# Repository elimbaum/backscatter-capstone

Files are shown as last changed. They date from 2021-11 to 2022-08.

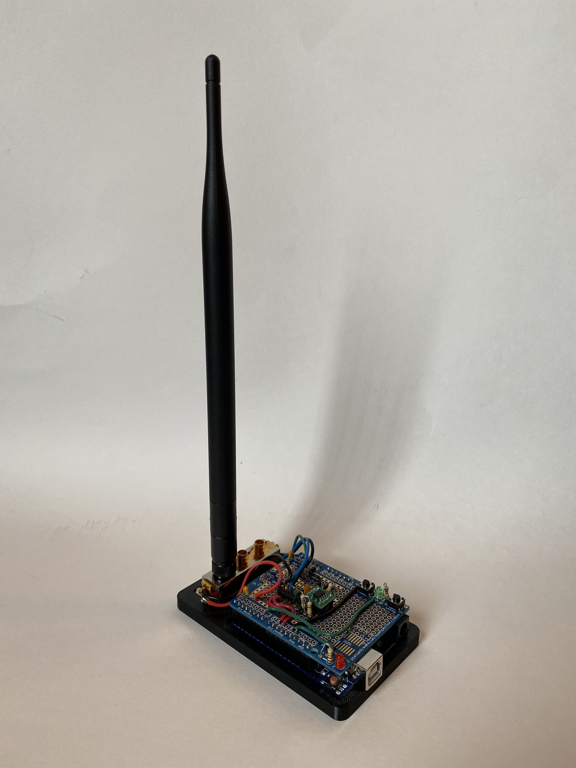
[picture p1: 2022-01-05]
img/full antenna.jpeg

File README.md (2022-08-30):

# Low-power Backscatter Sensor Communications

*NSAP Capstone Project, 2021*

Eli Baum

Full report is available in `backscatter capstone.docx`.

Repo layout:

- `arduino`
    - Various experiments for the transmitter module.
    - Final prototype is in `full_proto`, using utilty functions in `util`
- `flowgraphs`
    - Various GNUradio flowgraphs
    - `proto/proto_decode.grc` is used to ingest samples from SDR for final prototype.
- `img`: images for report
- `print/case`: 3d printed transmitter enclosure
- `processing`
    - Various python experiments and decoders
    - Final prototype is `fm0/fm0_proto.py`
- `pseudocode`
    - explanatory pseudocode for both the transmitter and receiver

> MITRE Public Release Case Number: 22-2535

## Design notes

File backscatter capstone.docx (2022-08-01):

| MP220434 MITRE PRODUCT
| Low-Power Backscatter Sensor Communications
Project No.: GNA051.N300.301.CA | National Security Accelerator Program Capstone Project
The views, opinions and/or findings contained in this report are those of The MITRE Corporation and should not be construed as an official government position, policy, or decision, unless designated by other documentation. ©2022 The MITRE Corporation. All rights reserved. McLean, VA | Eli Baum January 2022

Abstract

Wireless communications systems are frequently constrained by size and power. Occasionally, it may be desirable to communicate with extremely small, low-power systems. Here, we present a backscatter sensor communications platform, which modulates and reflects ambient radio frequency signals, rather than radiating its own signals in the manner of a standard radio transmitter. Our prototype system can communicate at approximately one kilobit per second over a distance of 1.3 meters. We draw on past research to show that more advanced schemes could permit greater transmission speeds over more useful distances. One possible application for such technology includes distributed low-power sensing.

Acknowledgments

I would like to thank Dr. Michael Balazs, Andy Chapman, and Terri Roberts of MITRE’s National Security Accelerator Program for their support and encouragement.

Samantha Palazzolo, Terry Roberts, Evan Ding, and Eric Renda provided invaluable technical guidance, and helped me find my footing in the early days of my career at MITRE.

Table of Contents

# 1 Introduction

Wireless communications systems require significant power and can be rather large due to the analog circuitry required to modulate and amplify radio signals. Here, we propose a method of using backscatter technology to build extremely low-power wireless sensors. Without the normal requirements of radio transmitters, these backscatter sensors can be small, cheap, and long-lived; furthermore, since they emit no power, they are difficult for an adversary to detect.

A backscatter transmitter modulates reflected radio signals from another source, rather than radiating signals that it generates. Since the transmitter must do nothing more than switch a transistor at a given frequency, it requires very little power: the power requirements for communication are shifted to the signal source (or “illuminator”) and processing is fully offloaded to a receiver, which may be attached to larger ground, air, or maritime platforms, where power and size are less constrained.

Backscatter systems can also be cheaply manufactured to provide distributed sensing capabilities. Users could distribute thousands of sensors across an area of interest and fly data-collection drones over the sensor field. Alternatively, a fixed station could read data in real time from sensors at a distance. Such deployments have already been validated in a prototype soil-moisture sensing network.[^1]

In this prototype, a software-defined radio (SDR) is used to generate a fixed-frequency tone at 915 MHz. The sensor modulates data at approximately 150 kHz; the receive side of the SDR is therefore tuned to 915.15 MHz. We attach a magnetic sensor to demonstrate one possible application. However, this demonstration is not the limit of backscatter sensing technology: academic research has demonstrated the ability for relatively complex backscatter systems to be powered entirely by harvested ambient radio frequency energy,[^2] while other studies have used custom waveforms to receive backscatter signals over distances of more than a kilometer.[^3] Furthermore, other environmental illuminators may be used, including broadcast TV or radar, removing the requirement for a separate transmitter.

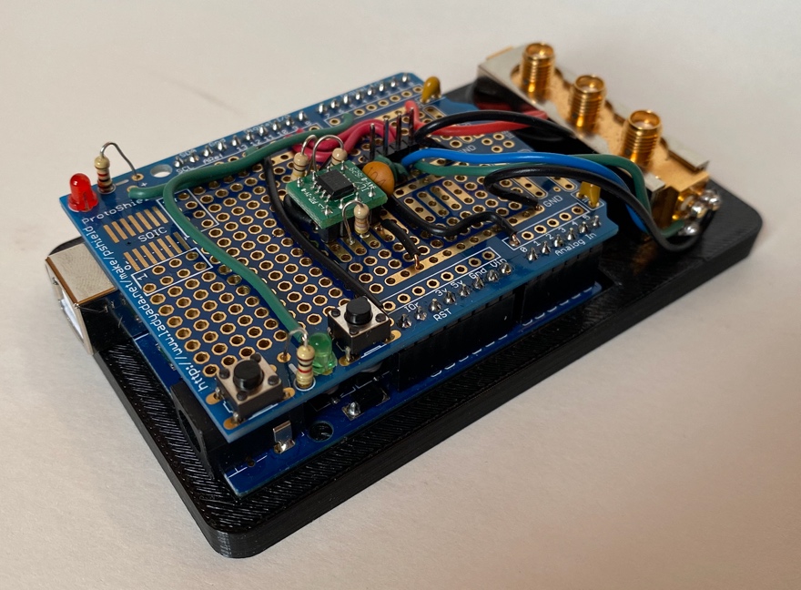
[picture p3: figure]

Figure 1: Our backscatter sensor module. The bulk of the current module is an Arduino. The green circuit board is a magnetic sensor; the RF switch is in the rear.

# 2 Backscatter Communications

## Theory

Backscatter communication may seem counterintuitive compared to standard wireless communication systems. The following analogy should help clarify this mode of transmission.

Consider two parties, Alice and Bob, who wish to communicate with each other, across some significant distance, at night. (For the purposes of argument, assume a line of sight exists between them.) The simplest method for Alice to send a message would likely be for her to point a flashlight at Bob and modulate its intensity according to some scheme (say, Morse code). Bob could record Alice's pulses of light and translate them into a message.

However, there are several drawbacks to this system. Alice must carry a flashlight, which may be heavy, require large power supplies, and generate significant heat. Additionally, if Alice would like to communicate covertly (or is trying to hide her location), a flashlight might be too easy for an adversary to detect.

Alice comes up with an alternative scheme: she carries a mirror which she uses to carefully reflect moonlight in Bob's direction. The resulting light will be much dimmer, from Bob's perspective, but Alice no longer needs a flashlight.

Alice and Bob soon run into an issue – if the moon is not in the sky, or it is cloudy, they are unable to communicate. Seeking more reliable communication, Bob sets up a lantern at a third location; Alice can once again either reflect, or not reflect, the light from the lantern towards Bob.

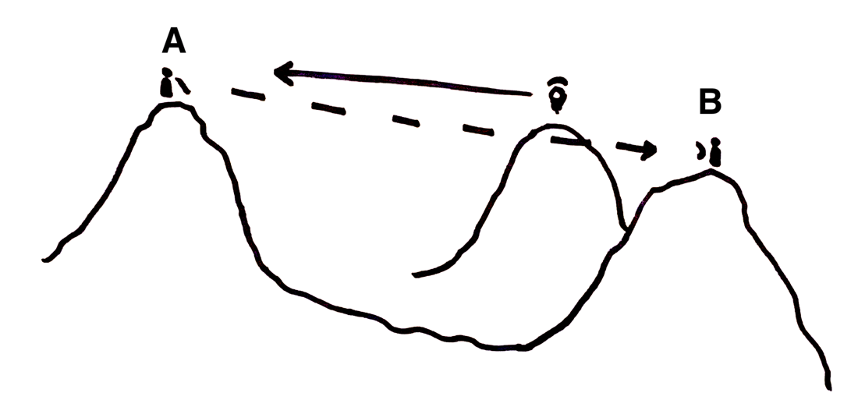
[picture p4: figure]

Figure 2: Alice stands on the left hill with a mirror. Bob places a lantern on the central hill and stands on the rightmost hill.

One problem remains: how can Bob see Alice's dim reflections, when the lantern is so much brighter? Perhaps Bob is in a shadow from his lantern and takes advantage of directionality. However, imagine a fluorescent mirror – that is, one which changes the wavelength of reflected light. Then, Bob could filter the wavelength of light coming from his lantern; only Alice's signal will remain.

Many of the concepts (and compromises) discussed above apply equally well to radio communications. The final scenario – where Bob illuminates Alice's color-changing reflector and detects the return signal – closely mirrors how backscatter communications works.

In this prototype, we use an SDR as both illuminator and detector. The transmit (TX) end of the SDR broadcasts a constant-frequency cosine tone; this is similar to Bob's lantern. The analog of the mirror is an antenna connected to the RF switch, which can either reflect or attenuate the illuminating signal.

For the “color-changing” component of Alice's mirror, we take advantage of constructive interference: given two signals A and B , with respective frequencies f_A and f_B , the addition of those two signals A+B will appear to have a frequency component at f_A ±f_B .[^4]

In this prototype, the cosine illuminator is transmitted at 915 MHz ( =f_A ); the sensor module is configured to toggle the RF switch at approximately 150 kHz ( =f_B ). Therefore, we expect artifacts to appear at 915±0.15 MHz . By tuning the receive (RX) side of the SDR to 915.15 MHz and keeping its bandwidth below 300 kHz (we use 200 kHz, the minimum of our hardware), interference from the transmitter is entirely eliminated. At this point, the reflected signal can be modulated in various ways.

In the national security domain, backscatter was perhaps most famously used by the Soviet Union during their bugging of the American Embassy in Moscow with “The Thing.” (https://en.wikipedia.org/wiki/The_Thing_(listening_device)) This project is inspired by that use case, but we also consider witting, environmental sensing applications (rather than covert espionage uses) for backscatter technology.

## A Word on RFID

Some commercial radio frequency identification (RFID) systems use backscatter technology. These systems are not extensible, and provide no way to transmit sensor data, as was desired here – instead, they generally transmit a fixed identification number – but they may provide future avenues for exploration.

The most well-known of such technologies is passive RFID, commonly encountered in electronic access control systems and contactless payment. In these systems, a tag reader generates an "interrogation" signal which is then reflected, and modulated, by the tag. Often (as in the case of a badge reader), the tag contains no power supply of its own, and instead harvests power from the interrogation signal itself.

Usually, passive systems work only at sufficiently small distances where the reader and tag antennas can magnetically couple (on order of centimeters); no true radio signals are exchanged. This region is known as the “near field.” However, some passive RFID systems do indeed work via radio waves (or the “far field”) in a manner similar to the backscatter communication module presented here – certain electronic toll collection systems are a common example.[^5]

Passive RFID contrasts with active RFID, which operates more like a normal wireless transmitter. Here, the interrogation signal "wakes up" the RFID tag, which then replies using its own dedicated transmitter. Such systems operate over greater distances, and with lower error, but require their own batteries and use much more power than purely reflective systems.

# 3 Prototype System

The prototype backscatter sensor module consists of an Arduino Uno (with an ATmega328 microcontroller), an RF switch, and a magnetic sensor. We take readings from the magnetic sensor, process them on the Arduino, and transmit data using backscatter. The SDR used was a USRP B210, but any similar SDR should work.

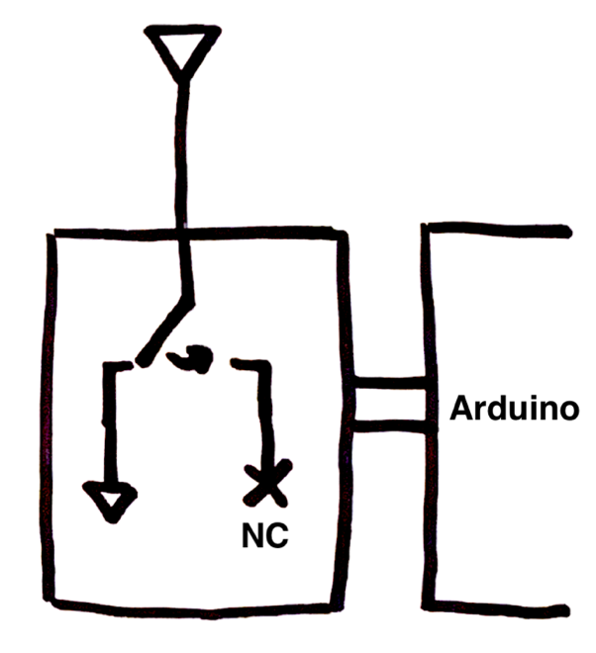
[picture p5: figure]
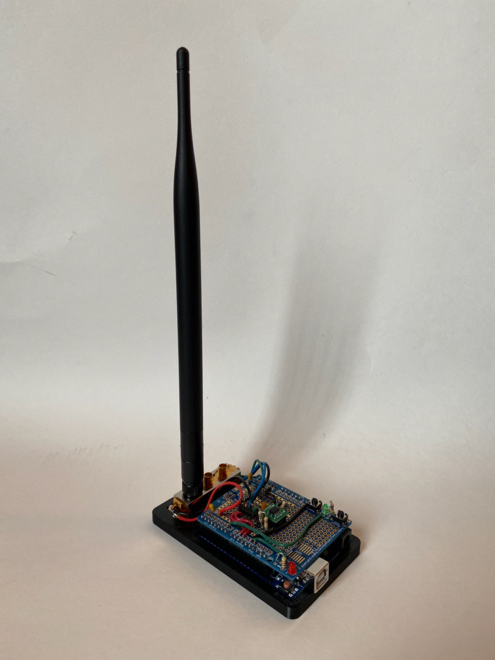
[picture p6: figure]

Figure 3: A diagram of the hardware setup, left. The antenna is either grounded (through a 50Ω resistor), or not connected. The completed sensor module, right.

## Physical Layer

The physical layer consists of the actual modulation of information onto the 915 MHz carrier wave. We designed a simple physical layer for ease of implementation and rapid prototyping.

### Hardware

The centerpiece of this prototype is an absorptive single-pole double-throw (SPDT) RF switch (Minicircuits ZX80-DR230-S+ (https://www.minicircuits.com/WebStore/dashboard.html?model=ZX80-DR230-S%2B)). The switch is connected to one of the microcontroller’s timer compare outputs, which oscillates at approximately 150 kHz. We connect an antenna to only one of the switch's ports and leave the others disconnected.

When the switch is in the open position, the antenna is connected to the unterminated center port. Therefore, incoming RF will be reflected. When the switch is closed, the antenna is terminated to ground via an internal 50Ω load, so all energy will be absorbed.

### Amplitude Shift Keying

We use amplitude-shift keying (ASK) to modulate data; this is the simplest scheme that could be used to build a viable prototype.

We experimented with frequency-shift keying (FSK) but decided not to move forward with it. FSK provides superior information density but is less noise-tolerant and more computationally complex to decode. Furthermore, the usefulness of an FSK system was limited by the granularity of the microcontroller's internal oscillator.

Other schemes, such as phase-shift keying (PSK) and quadrature amplitude modulation (QAM) were not possible with the hardware available on the sensor module. The RF switch contained a purely resistive internal load; phase-related modulations would only be possible with reactive (i.e., capacitive or inductive) loads. A fieldable backscatter solution would likely require more advanced hardware capable of these advanced modulation schemes.

### FM0 Encoding

Once we can modulate the signal, the next problem is to send bits. We need a clock recovery method – how do we align our receiver's data stream with that of our reflector? In this prototype, we have used FM0 encoding, an extremely simple run-length limited (RLL) code. RLL codes are designed to contain sufficient transitions to enable clock recovery; without FM0, a string of identical values could be difficult to differentiate.

In fact, FM0 is quite similar to Morse code. One is encoded as a long pulse, while zero is encoded as two short pulses (hence the “FM” or “frequency modulation” in its name). The actual level of these pulses is unimportant; rather, we only measure their transitions. In practice, after every bit, we toggle the signal, but for a 0, we also toggle halfway through that bit period. For example, to send the data 0110, we encode:

Data | X | 0 | 1 | 1 | 0 | X
Pulses | X | SS | L | L | SS | X
Transmit | 0 | 10 | 11 | 00 | 10 | 1

where SS represents two short pulses; L represents one long pulse.

While this is not a particularly efficient scheme (it takes 2 symbols to send one bit, making FM0 a rate-½ code), it is simple to implement and appropriate for prototyping.

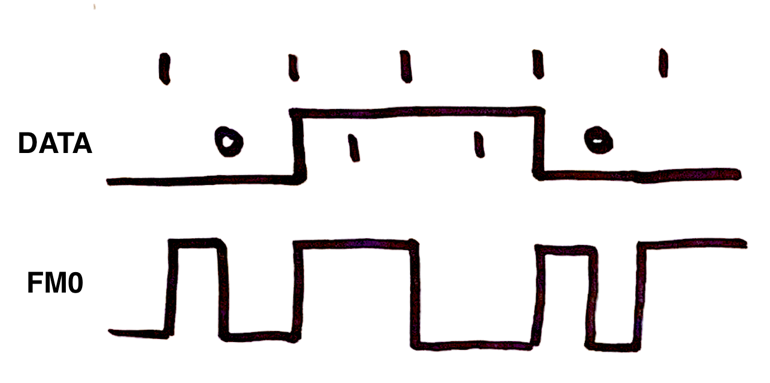
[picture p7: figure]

Figure 4: Example FM0 encoding of data.

## Packet Layer

Various data-transmission strategies are possible; we chose continuous data transmission since this is simple and beneficial for demonstration purposes. We designed a packet format, as follows:

Access Code | 32 bits: 0xe15ae893
Sequence Number | 8 bits
Data Length in bytes | 8 bits
Data | 8 bits per reading

The access code, 0xe15ae893, is a commonly-used non-cyclical access code.[^6] This access code correlates poorly with itself at all offsets except zero, which makes it easy for the receiver to synchronize with the incoming packet.

The sequence number provides some level of error detection. It is incremented for each packet (overflowing from 255 to 0); the decoder only accepts a packet if the decoded sequence number is one greater than the previous. More advanced schemes with error detection and correction would be desirable in a fieldable system. We implemented a Hamming encoder and decoder but decided not to include it in the prototype for the sake of simplicity.

# 4 Decoder Implementation

The Python decoder is implemented as a series of layers. Each layer receives data from the one above, provides some processing functionality, and passes data down.

1. SDR sampling. GNU Radio is used to read samples from the SDR.
2. ASK decoding. A simple ASK decoder converts samples into binary values. Since the sampling rate is much higher than the symbol rate (by about two orders of magnitude), there are multiple digitized samples per actual ASK symbol.
3. Pulse length determination. FM0 decoding depends on the length of pulses in the input stream. First, we perform a coarse search – this layer simply returns the time between binary transitions.
4. Pulse length clustering. Due to noise and timing inaccuracies, not all pulses will precisely match the expected short or long length. In this step, we cluster the received pulses around their estimated true length and account for noise. For example, a burst of noise in the middle of a long pulse of length 2 may make that pulse look like three short pulses of lengths 0.9, 0.2, and 0.9. This layer detects the noisy burst and converts the set of pulses into the correct long pulse.
5. FM0 decoding. Now, we can turn pulses into symbols: two short pulses are a zero; one long pulse is a one.
6. Packet decoding. Each packet begins with the non-cyclical access code. Using a sliding 32-bit window, we correlate against the access code to find the start of a packet (the correlation reaches a maximum at perfect alignment).[^7] Next, we check the sequence number, and if correct, we read the length, and then the prescribed number of data bytes.
7. Data graphing. Finally, data values are plotted in real time with matplotlib.

# 5 Sensor Demonstration

The focus of this project was on backscatter communication itself, not on the data sent over the backscatter link. However, to demonstrate real-time communication capabilities, we add a magnetic sensor to the backscatter module. We take a moving average of the sensor readings and send 16 8-bit values per packet. With these parameters, each packet is therefore 176 bits. At a symbol rate of 2000 baud, we can send 1000 bits per second, giving about 5.7 packets, or 91 readings, per second.

An example data transmission is shown below. The sensor was not turned on until t=5 ; values prior to that point are noise. A value of 127 represents a magnetic field of zero, with values above or below 127 reflecting a positive or negative magnetic field, respectively. Over the course of one minute, a magnet was moved around the sensor in various orientations.

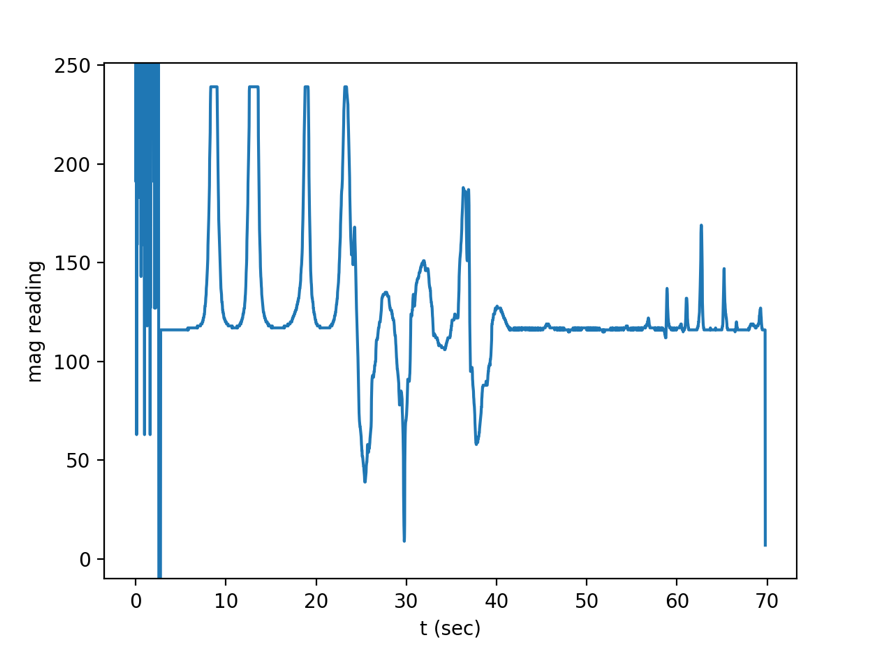
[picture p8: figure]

Figure 5: A plot of sensor readings transmitted via backscatter.

# 6 Results

This prototype was meant as a proof of concept for future study and has demonstrated that backscatter is a viable method for low-power, low-bitrate communications. We hid a magnet inside of a toy garbage truck and demonstrated how the backscatter sensor module was able to detect the presence of the truck. Of course, with other sensors, various environmental parameters of interest could be measured, recorded, and analyzed.

A summary of the test parameters follows:

- Physical layout
- 132 cm between transmitter and sensor
- 132 cm between receiver and sensor
- Approximately 100 cm between transmitter and receiver (to prevent in-band interference)
- RF parameters
- TX gain: 89 dB (SDR maximum)
- RX gain: 26 dB
- Lowpass filter width: 3 kHz
- Frequency calibration: -1.4 kHz
- Packet parameters
- 2000 symbols per second (1000 bps)
- ~ 91 measurements transmitted per second

Placement of the TX and RX antennas in relation to the sensor is an important factor for the successful operation of the sensor module. At very close distances (on order of the wavelength of the carrier wave), magnetic coupling dominates, and the system is more akin to a passive near-field RFID system. For the 915 MHz carrier used here, one wavelength is 32.76 cm. To ensure we are operating in the RF far-field, antenna separation should be two wavelengths or more.

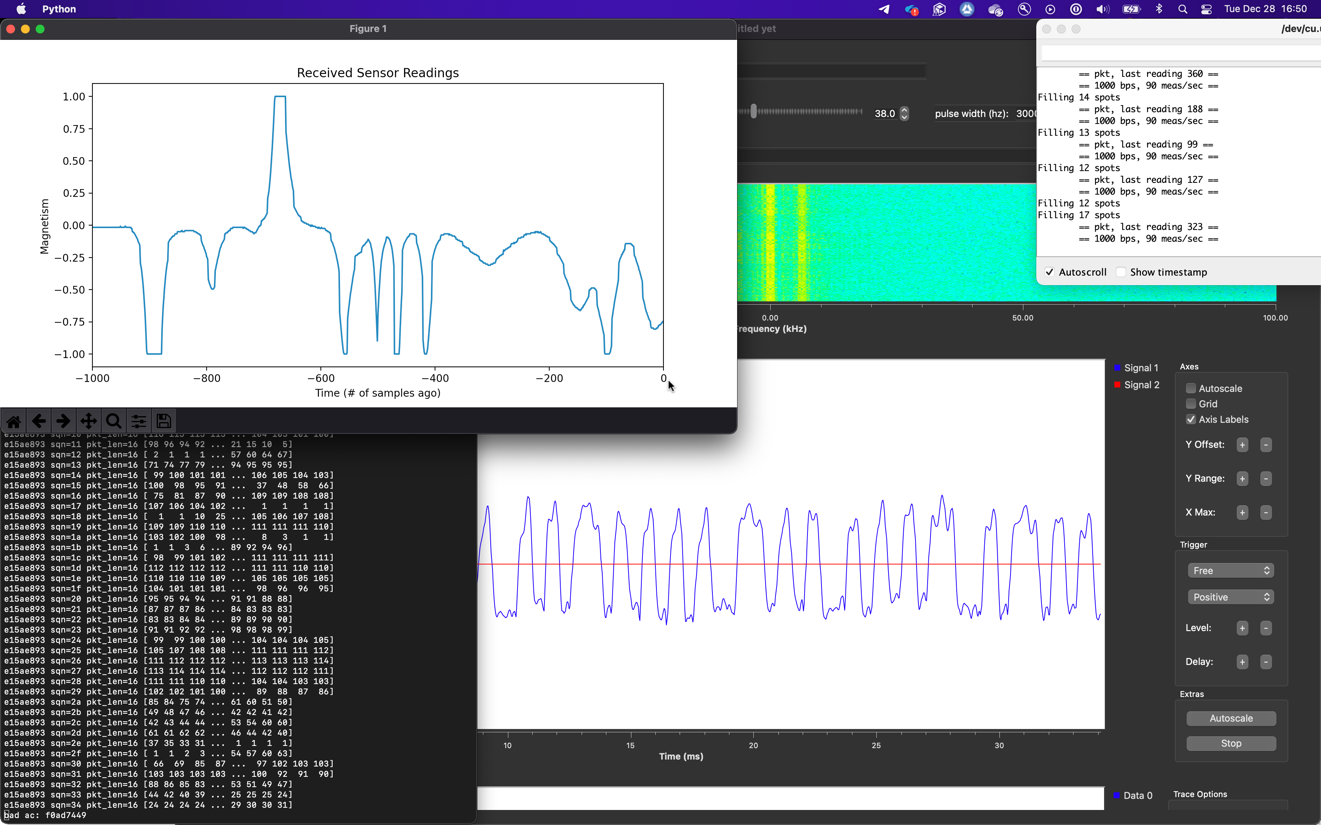
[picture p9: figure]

Figure 6: A screenshot of the full software stack. Clockwise from top right: 1) debug output from the microcontroller; 2) a time-domain view of the received ASK waveform; 3) debug output from the Python decoder; 4) processed magnetic sensor readings.

## Caveats and Future Work

After many unreliable tests, we realized (or at least suspect) that due to the short distances used in this demonstration, poor performance was occurring when the backscatter antenna was in a node (or null) of the transmitting tone. The radio waves are not traveling far enough for multi-path effects to make a difference, and since the illumination signal is a single sine wave, there will exist some nulls in the signal strength. We solved this problem by ensuring the backscatter sensor was some multiple of the wavelength away from both the TX and RX sensors (here, about 33 cm). In more realistic environments, frequency hopping or spread-spectrum modulation could help mitigate this problem.

We are also interested in exploring more robust, higher bitrate transmissions. As mentioned above, there are many physical layer modulation schemes, such as FSK or PSK, that could enable faster transmission. Frequency-swept chirps, as used in LoRa communications, have shown success in backscatter systems, with particularly impressive performance over long distances. However, different RF hardware (such as reactive components) would be required (as well as a high-precision digital timer), particularly to enable phase shifts. Even so, we caution that high bandwidth communications will likely not be possible with backscatter: since the returned power is much lower than a normal radio transmitter, the channel capacity is necessarily limited.

Additionally, more complex coding schemes (rather than FM0) would allow for a greater symbol rate and more efficient clock recovery; error correction would also be an improvement over naive sequence number checking.

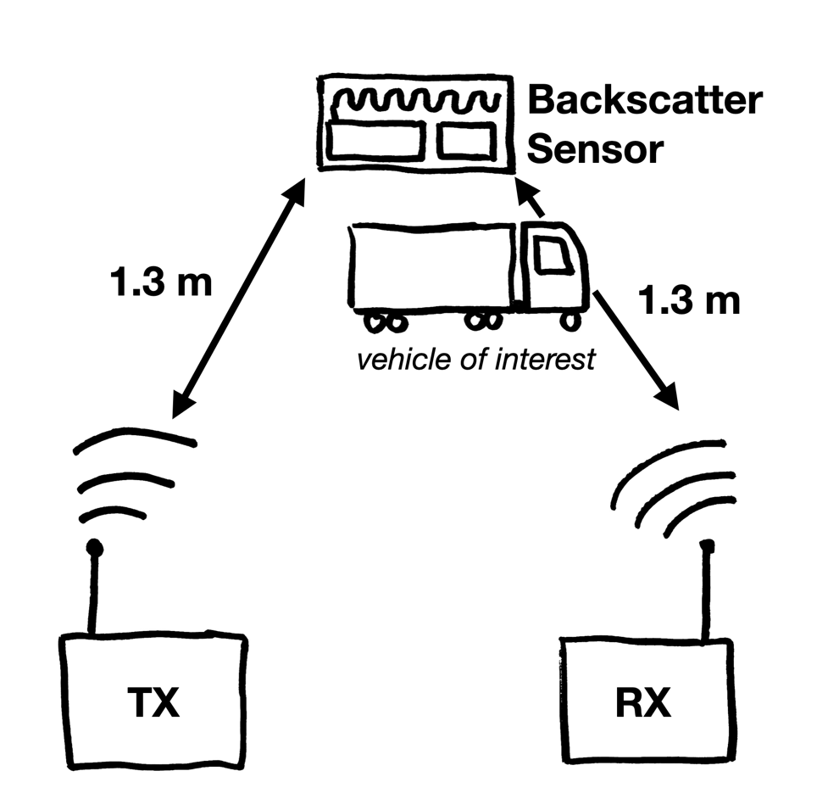
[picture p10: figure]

Figure 7: Overview of our test setup. Transmit (TX) and Receive (RX) are in this case run via the same software-defined radio, but with spaced-apart antennas.

# 7 Conclusion

Backscatter technology will not replace standard wireless transmission in areas where it is currently used. However, due to its low cost, power, and size requirements, backscatter has the potential to revolutionize distributed sensing applications. We demonstrate a prototype backscatter sensing module that can wirelessly transmit 1000 bps of data reliably over distances of about a meter. For applications where low-bitrate communications are acceptable, we hope that future research could significantly increase the maximum transmission distance. Alternatively, the maximum bitrate of the system could be improved, allowing for for other kinds of communications data, such as text or audio.

## Possible Use Cases

Consider a hypothetical scenario where an organization wishes to monitor vehicle traffic in a large area. Rather than installing thousands of vibration sensors with high-power transmitters (say, cellular modems), low power backscatter sensors could be distributed along roads in the area. These sensors would have much longer lifespans (and be harder to detect); from time to time, friendly vehicles with backscatter transmitter/receiver pairs could drive by and offload data from the sensors.

Backscatter would also be beneficial in maritime ports, where sensors could be attached to shipping containers. This deployment would, in a sense, be a form of advanced RFID – but a more complex backscatter tag could relay collected data from the container’s voyage, rather than just an identification code. When a container arrives in port, cranes or other autonomous systems would be able to ingest the data, all while requiring no power supply on the container itself.

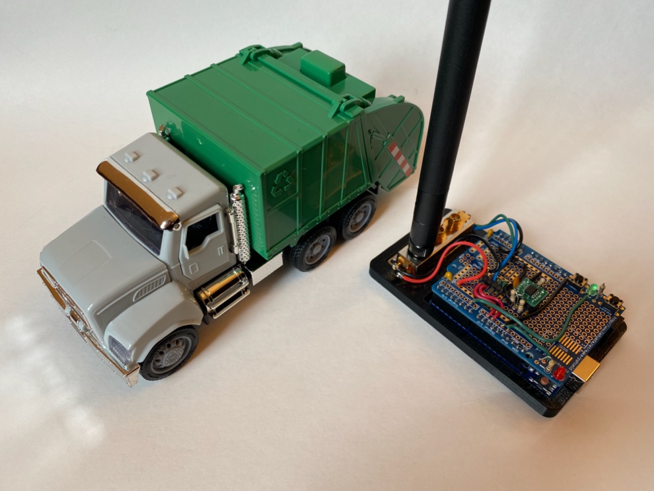
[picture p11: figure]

Figure 8: A neodymium magnet was installed inside a toy garbage truck to demonstrate a possible use case.

###### Software

The full code for this project is available on Github:

https://github.com/elimbaum/backscatter-capstone

Below, we include pseudocode for both the reflector (transmitter) and receiver to provide some insight into their operation.

###### Reflector

# Reflector Pseudocode

# Continuously takes sensor readings and sends them out

# Target: Arduino Uno (ATMega328)

setup:

configure i/o

configure timers

# load access code, sqn, length

enqueue packet header

loop:

s = count empty slots in the queue

repeat s times:

r = measure magnetic sensor

enqueue r

if packet is full:

# load access code, sqn, length

enqueue packet header

# Runs every 500 microseconds

timer interrupt:

pull a bit off the queue

if bit == 1:

toggle RF switch at 150 kHz

else:

stop toggling RF switch

###### Receiver

# Receiver Pseudocode

# This section runs in GNURadio

receiver:

load samples from radio

retune to ASK center frequency

low pass filter

convert complex values to magnitudes

send to decoder

# All other sections run in Python

decoder:

ingest raw values from receiver

binary slice

# coarse pulse extraction

pulses = run-length encode sliced data

if any pulse is below noise threshold:

combine adjacent pulses

symbols = FM0 decode pulses

packet = unpack symbols

match = correlate packet against access code

if no match:

continue

sqn = read sequence number

if sqn is out of order:

continue

n = read packet length

r = read n bytes

add r to sensor_values

plot:

continuously replot sensor_values

[^1] S. Daskalakis, S. D. Assimonis, E. Kampianakis and A. Bletsas, "Soil Moisture Scatter Radio Networking with Low Power," in IEEE Transactions on Microwave Theory and Techniques, vol. 64, no. 7, pp. 2338-2346, July 2016. doi:10.1109/TMTT.2016.2572677
[^2] Vamsi Talla, Bryce Kellogg, Shyamnath Gollakota and Joshua R. Smith. 2017. Battery-Free Cellphone. PACM Interact. Mob. Wearable Ubiquitous Technol. 1, 2, Article 25 (June 2017), 20 pages. doi:10.1145/3090090
[^3] Vamsi Talla, Mehrdad Hessar, Bryce Kellogg, Ali Najafi, Joshua R. Smith and Shyamnath Gollakota. 2017. LoRa Backscatter: Enabling The Vision of Ubiquitous Connectivity. Proc. ACM Interact. Mob. Wearable Ubiquitous Technol. 1, 3, Article 105 (September 2017), 24 pages. doi:10.1145/3130970
[^4] This effect is often noted in music, where the resulting perceived beat frequency can be used to tune an instrument, but we can just as easily create a frequency-shifting effect at radio frequencies.
[^5] Lazar N. Spasovic, Wen Zhang, Athanassios K. Bladikas, Louis J. Pignataro, Edip Niver, and Stanley Ciszewski. 1995. Primer on Electronic Toll Collection. Transportation Research Record No. 1516, Intelligent Transportation Systems. https://trid.trb.org/view/453148
[^6] GNURadio (https://wiki.gnuradio.org/index.php/Correlate_Access_Code) cites this access code “historically interesting” but we find few other references to it on the Internet. Regardless, the access code worked well for our use case.
[^7] In a later version of the prototype, we use the Hamming weight of the bitwise XOR rather than statistical correlation since this ends up producing fewer false positives. However, for binary values, these two measures are similar.

2-2 Approved for Public Release; Distribution Unlimited. Public Release Case Number 22-2392

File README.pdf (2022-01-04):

NSAP Capstone Project, 2021

Eli Baum

topic sentences
active voice

Wireless communications systems require significant power and can be rather large due to the analog circuitry required to modulate radio signals. Here, we propose a method of using backscatter technology to build extremely low-power wireless sensors. Without the normal requirements of radio transmitters, these backscatter sensors can be small, cheap, and long-lived; furthermore, since they emit no power, they are difficult for an adversary to detect.

A backscatter transmitter modulates reflected radio signals from another source, rather than radiating signals that it generates. Since the transmitter must do nothing more than switch a transistor at a given frequency, it requires very little power: most of the power and processing requirements for communication are shifted to the signal source (or "illuminator") and receiver, which may be attached to larger ground, air, or maritime platforms, where power and size are less constrained.

Backscatter systems can also be cheaply manufactured to provide distributed sensing capabilities. Warfighters could distribute thousands of sensors across an area of interest and fly data-collection drones over the sensor field. Or, a fixed station could read data in real time from hidden sensors at a distance.

In this prototype, an SDR is used to generate a fixed-frequency tone at 915 MHz. The sensor modulates data at approximately 150 kHz; the receive side of the SDR is therefore tuned to 915.15 MHz. We attach a magnetic sensor to demonstrate one possible Sponsor-focused application. However, this demonstration is not the limit of backscatter sensing technology:

# Low-power Backscatter Sensor Communications

# Overview

academic research has demonstrated the ability for relatively complex backscatter systems to be powered entirely by harvested ambient radio frequency energy, while other studies have used custom waveforms to receive backscatter signals over distances of more than a kilometer.

Backscatter communication may seem counterintuitive compared to standard wireless communication systems. The following analogy may help clarify its operation.

Consider two parties, Alice and Bob, who wish to communicate with each other, across some significant distance, at night. (For the purposes of argument, assume a line of sight exists between them.) The simplest method for Alice to send a message would probably be for her to point a flashlight at Bob and turn it on and off under some modulation scheme (say, Morse code). Bob could record Alice's pulses of light and translate them into a message.

However, there are several drawbacks to this system. Alice must carry a flashlight, which may be heavy, require large power supplies, and generate significant heat. Additionally, if Alice would like to communicate covertly (or is trying to hide her location), a flashlight might be too easy for an adversary to detect.

Alice comes up with an alternative scheme: she carries a mirror which she uses to carefully reflect moonlight in Bob's direction. The resulting light will be much dimmer, from Bob's perspective, but Alice no longer needs a flashlight.

Alice and Bob soon run into an issue – if the moon is not in the sky, or it is cloudy, they are unable to communicate. Seeking more reliable communication, Bob sets up a lantern at a third location; Alice can once again either reflect, or not reflect, the light from the lantern towards Bob.

# Backscatter

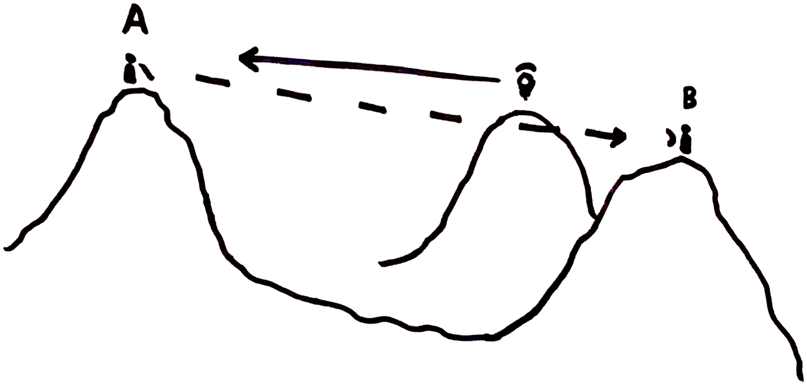
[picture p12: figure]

Alice stands on the left hill with a mirror. Bob places a lantern on the central hill, and stands on the rightmost hill.

One problem remains: how can Bob see Alice's dim reflections, when the lantern is so much brighter? Perhaps Bob has a shade or lenses. However, imagine a phosphorescent mirror; that is, one which changes the color of reflected light. Then, Bob could filter the wavelength of light coming from his lantern; only Alice's signal will remain.

Many of the concepts (and compromises) discussed above apply to radio communications, as well. The final scenario – where Bob illuminates Alice's color-changing reflector and detects the return signal – closely mirrors how backscatter radio communications works.

In this prototype, we use an SDR as both illuminator and detector. The transmit (TX) end of the SDR broadcasts a constant-frequency cosine tone; this is similar to Bob's lantern. The analog of the mirror is an antenna connected to the RF switch, which can either reflect or attenuate the illuminating signal.

For the "color-changing" component of Alice's mirror, we take advantage of constructive interference:

Given two signals | and , with respective frequencies | and | , the addition of those two
signals | will appear to have a frequency component at | . (This is often noted in
music, where the perceived beat frequency can be used to tune an instrument, but we can just as easily create a frequency-shifting effect at radio frequencies.) In this prototype, the cosine
illuminator is transmitted at 915 MHz ( | ); the sensor module is configured to toggle the RF
switch at approximately 150 kHz ( | ). Therefore, we expect artifacts to appear at
A | B | fA | fB
A + B | fA ± fB

= fA
| = fB | | 915 ± 0.15

MHz. By tuning the receive (RX) side of the SDR to 915.15 MHz, and keeping its bandwidth below 300 kHz (we use 200 kHz, the minimum of our hardware), interference from the transmitter is entirely eliminiated. At this point, the reflected signal can be modulated in various ways. See Physical Layer, below, for further details.

In the national security domain, backscatter was perhaps most famously used by the Soviet Union during their bugging of the American Embassy in Moscow with "The Thing." (https://en.wikipedia.org/wiki/The_Thing_(listening_device)) This project is inspired by that use case, but we consider witting, environmental sensing applications (rather than covert espionage uses) for backscatter technology.

Some commercial radio frequency identification (RFID) systems use backscatter technology. These systems are not extensible, and provide no way to transmit sensor data, as was desired here – instead, they generally transmit a fixed identification number – but they may provide future avenues for exploration.

The most well-known of such technologies is passive RFID, commonly encountered in electronic access control systems and contactless payment. In these systems, a tag reader generates an "interrogation" signal which is then reflected, and modulated, by the tag. Often (as in the case of a badge reader), the tag contains no power supply of its own, and instead harvests power from the interrogation signal itself.

Usually, passive systems work only at sufficiently small distances where the reader and tag antennas can magnetically couple (on order of centimeters, and such coupling attenuates much faster); no actual radio signals are exchanged. However, some passive RFID systems do indeed work via radio waves in a manner similar to the backscatter communication module presented here – certain electronic toll collection systems are a common example.

Passive RFID contrasts with active RFID, which operates more like a normal wireless transmitter. Here, the interrogation signal "wakes up" the RFID tag, which then replies using its own dedicated transmitter. Such systems operate over greater distances, and with lower error, but of course use much more power than purely reflective systems.

The prototype backscatter sensor module consists of an Arduino (with an ATmega328 microcontroller), an RF switch, and a magnetic sensor. We take readings from the magnetic sensor, process them on the Arduino, and transmit data using backscatter.

## A Word on RFID

# Prototype Components

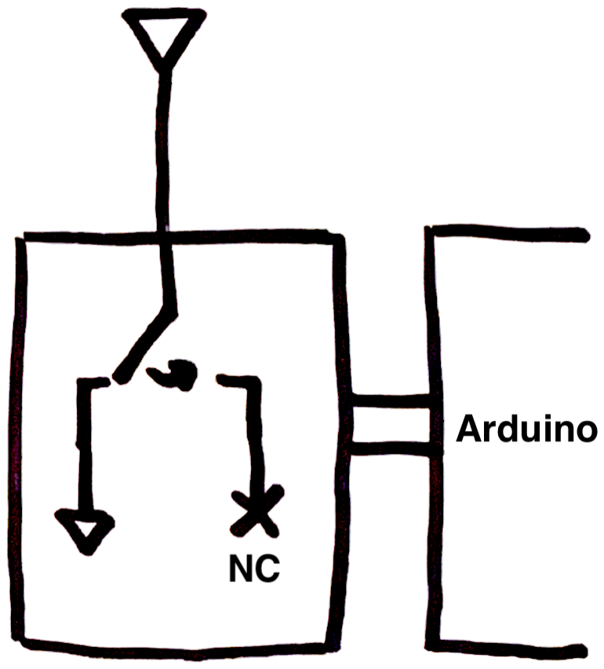
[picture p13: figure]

A diagram of the hardware setup. The antenna is either grounded (through a 50Ω resistor, or not connected.)

The physical layer consists of the actual modulation of information onto the 915 MHz carrier wave. We chose a simple physical layer for ease of implementation and rapid prototyping.

The centerpiece of this prototype is an RF switch (Minicircuits model ZX80-DR230-S+). The switch is connected to the output of one of the ATmega's timer compare outputs; the timer is configured to oscillate at approximately 150 kHz. We connect an antenna to only one of the switch's ports and leave the others disconnected.

When the switch is in the open position, the antenna is connected to the unterminated center port. Therefore, incoming RF will be reflected. When the switch is closed, the antenna is terminated with an internal 50Ω load, so all energy will be absorbed.

We use amplitude-shift keying (ASK) to modulate data; this is the simplest scheme that could be used for the purposes of a viable prototype.

We experimented with frequency-shift keying (FSK) but decided not to move forward with it. FSK

## Physical Layer

### Hardware

### Amplitude Shift Keying

provides superior information density but is less noise-tolerant and more computationally complex to decode. Furthermore, the usefulness of an FSK system was limited by the granularity of the microcontroller's internal oscillator.

Other schemes, such as phase-shift keying (PSK) and quadrature amplitude modulation (QAM) were not possible with the hardware available on the sensor module. The RF switch contained a purely resistive internal load; phase-related modulations would only be possible with reactive (i.e. capacitive) loads. A fieldable backscatter solution would likely require more advanced hardware capable of these advanced modulation schemes.

Once we are able to modulate the signal, the next problem is to actually send bits. In particular, we need a clock recovery method – how do we align our receiver's data stream with that of our reflector's? In this prototype, we have used FM0 encoding, an extremely simple run-length limited (RLL) code. RLL codes are designed to contain sufficient transitions to enable clock recovery; without FM0, a string of identical values could be difficult to differentiate.

In fact, FM0 is quite similar to Morse code. 1 bits are encoded as a long pulse, while 0 is encoded as two short pulses (hence the "FM" or "frequency modulation" in its name). We do not care about the actual level of these pulses, but only their transitions: in practice, after every bit,

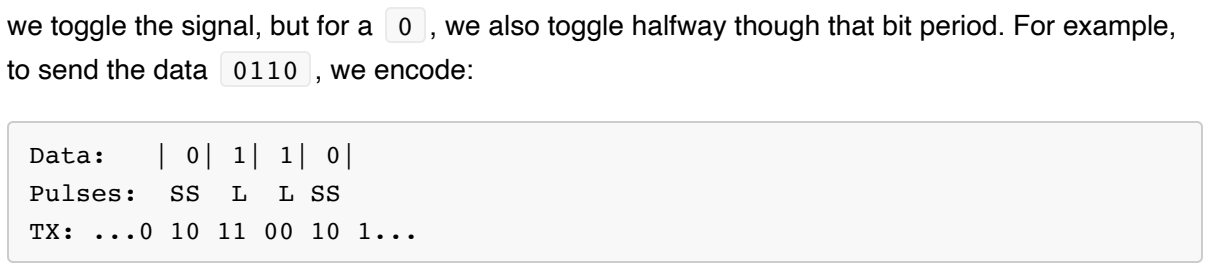
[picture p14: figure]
to send the data 0110 , we encode:; Data:; Pulses:

we toggle the signal, but for a 0 , we also toggle halfway though that bit period. For example,

FM0

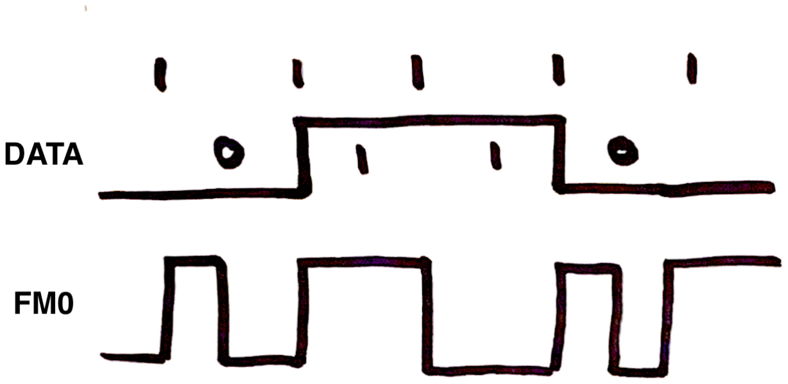
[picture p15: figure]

While this is not particularly efficient (it takes 2 symbols to send one bit, making FM0 a rate-1/2 code), it is simple to implement and appropriate for prototyping.

At this point, a fieldable system would also include error-detection and correction schemes to ensure reliable communication at a distance. We implemented a Hamming encoder/decoder, but decided not include it in the final prototype, since it was unnecessary for demonstration purposes.

Various data-transmission strategies are possible; we chose continuous data transmission, since this is simple and beneficial for demonstration purposes. We designed a packet format, as

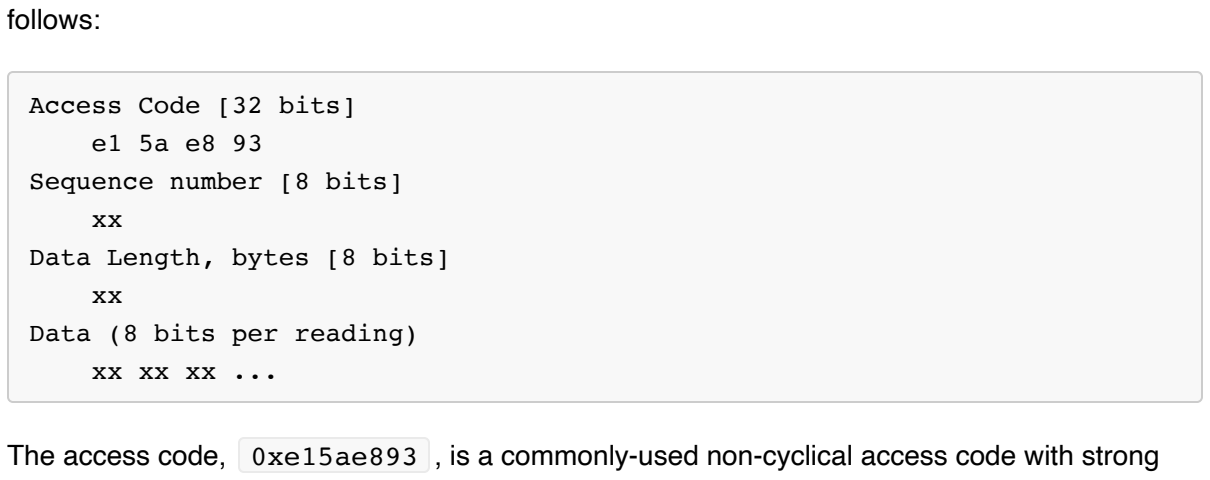
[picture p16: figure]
follows:; Access Code [32 bits] e1 5a e8 93 Sequence number [8 bits] xx Data Length, bytes [8 bits] xx Data (8 bits per reading) xx xx xx ...

The access code, 0xe15ae893 , is a commonly-used non-cyclical access code with strong auto-correlation properties. This makes it easy for the decoder to synchronize to the start of the packet: the access code correlates poorly with itself at all offsets except 0.

The sequence number provides some level of error detection, however – it is incremented for each packet (overflowing from 255 to 0); the decoder only accepts a packet if the decoded sequence number is one greater than the previous.

The focus of this project was on backscatter communication itself, not on the particular data sent over the backscatter link. Here, we add a magnetic sensor to the backscatter sensor, to demonstrate real-time communication capabilities. We take a moving average of the sensor readings and send 16 8-bit values per packet.

With these parameters, each packet is therefore 176 bits. At a symbol rate of 2000 baud, we can send 1000 bits per second. This gives about 5.7 packets per second, or 91 readings per second.

## Packet Layer

## Sensor Demonstration

The Python decoder is implemented as a series of layers. Each layer receives data from the one above, provides some processing functionality, and passes data down.

1. SDR sampling

GNURadio is used to read samples from the SDR.

2. ASK decoding

A simple ASK decoder converts samples into binary values. Since the sampling rate is much higher than the symbol rate (by about two orders of magnitude), there are multiple digitized samples per actual ASK symbol.

3. Pulse length determination

FM0 decoding depends on the length of pulses in the input stream. First, we perform a coarse search – this layer simply returns the time between binary transitions.

4. Pulse length clustering

Due to noise and timing inaccuracies, not all pulses will be the expected short or long lengths. In this step, we cluster the received pulses around their estimated true length, and also account for noise. For example, a burst of noise in the middle of a long pulse (say, of length 2) may make that pulse look like three short pulses (say, of lengths 0.9, 0.2, and 0.9). This layer detects the noisy burst and converts the set of pulses into the correct long pulse.

5. FM0 decoding

Now, we can turn pulses into symbols: two short pulses is a 0 ; one long pulse is a 1 .

6. Packet decoding

Each packet begins with the non-cyclical access code. We use a sliding 32-bit window, correlated against the access code, to find the start of a packet (the correlation* reaches a maximum at perfect alignment). Next, we check the sequence number, and if correct, we read the length, and then the prescribed number of data bytes.

* In a later version of the prototype, we use bitwise XOR rather than statistical correlation, since this ends up producing fewer false positives.

## Decoder Implementation

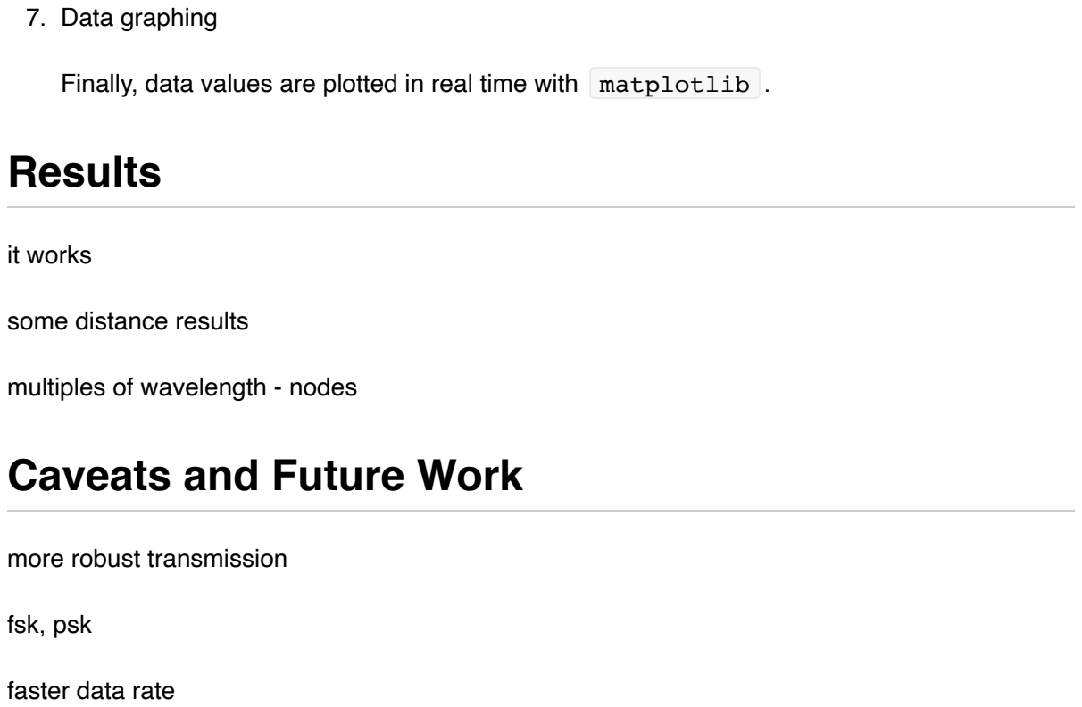
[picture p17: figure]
7. Data graphing; it works; some distance results; multiples of wavelength - nodes; more robust transmission; fsk, psk; faster data rate; Results; Caveats and Future Work

Finally, data values are plotted in real time with matplotlib .

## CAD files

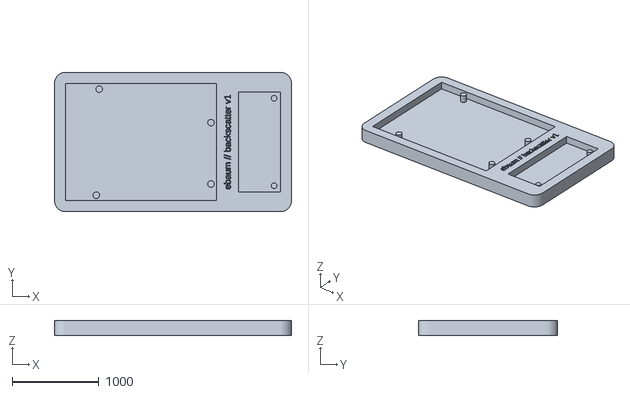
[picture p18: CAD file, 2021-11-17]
print/case/case_v1_inch.stl
2735.1 x 1607.4 x 167.6

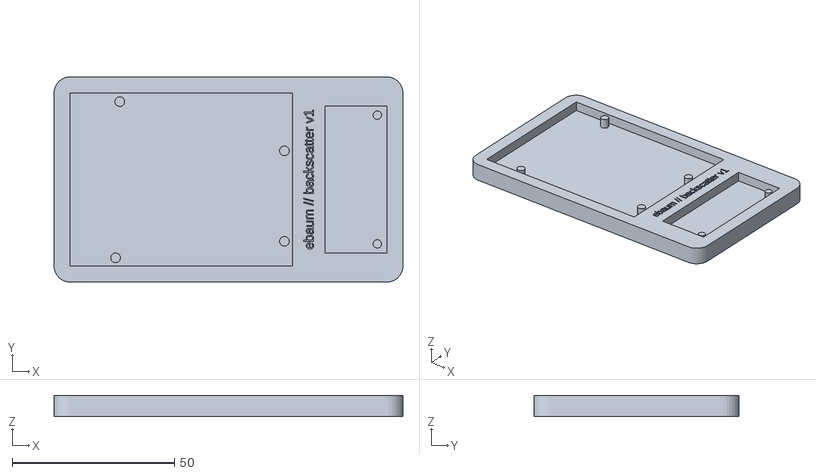
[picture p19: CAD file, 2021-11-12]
print/case/case_v1.stl
107.7 x 63.3 x 6.60

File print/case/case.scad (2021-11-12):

// units: mm
// x/y coordinates with USB port on left.

$fs = 0.01;

TOL = 0.001;

FULL = 10;

rf_switch = [19.07, 45.29, 2.6];
arduino = [68.61, 53.34, 3.6];

switch_arduino_sep = 10;

// underneath arduino
case_thickness = 3;

// border around arduino
case_border = 5;

// switch info
switch_hole_diam = 2.6;

switch_hole_location = [-2.92, 2.79];

// actually 3.2mm
arduino_hole_diam = 3;

// orientation: USB/pwr on left
arduino_hole_locations = [
    // lower left
    [14.0, 2.5],

    // lower right (outcrop)
    [66.1, 7.6],

    // upper right (outcrop)
    [66.1, 35.5],

    // upper left
    [15.3, 50.7]
];

text_depth = 0.5;

module components() {
    translate([0, 0, case_thickness]) {
        cube([arduino.x, arduino.y, FULL]);

        translate([arduino.x + switch_arduino_sep,
                    (arduino.y - rf_switch.y)/2, 0]) {
            cube([rf_switch.x, rf_switch.y, FULL]);
        }
    }
}

module case_outline() {
    linear_extrude(case_thickness + arduino.z) {
        minkowski() {
            square([arduino.x + switch_arduino_sep + rf_switch.x,
                    arduino.y]);
            circle(case_border);
        }

    }
}

module rf_hole() {
    cylinder(r = switch_hole_diam/2,
             h = case_thickness + rf_switch.z);
}

module arduino_hole() {
    cylinder(r = arduino_hole_diam/2,
             h = case_thickness + arduino.z);
}

module all_holes() {

    // arduino holes

    // rf switch holes
    translate([arduino.x + switch_arduino_sep + rf_switch.x,
                    (arduino.y - rf_switch.y)/2, 0])
    {
        translate(switch_hole_location) {
            rf_hole();
            translate([0, rf_switch.y - 2 * switch_hole_location.y, 0]) {
                rf_hole();
            }
        }
    }

    for (h=arduino_hole_locations) {
        translate(h) {
            arduino_hole();
        }
    }
}

module elitext() {
    translate([case_border + arduino.x,
                arduino.y/2,
                case_thickness + arduino.z - text_depth])
    rotate(90) {
        linear_extrude(text_depth + TOL)
        text("ebaum // backscatter v1",
                size=3,
                halign="center",
                valign="center");
    }
}

union() {
    difference() {
        case_outline();
        components();
        elitext();
    }
    all_holes();
}

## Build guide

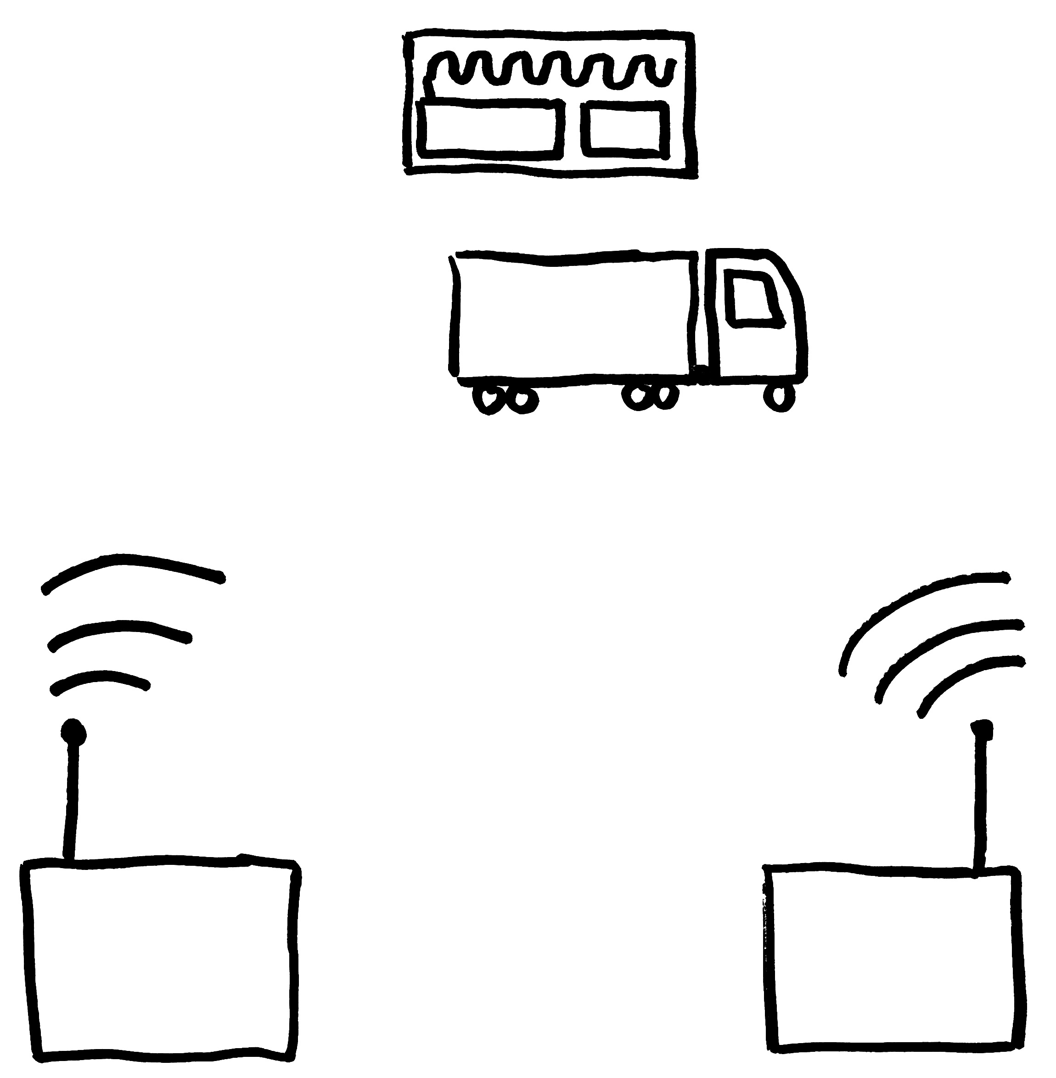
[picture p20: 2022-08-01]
img/setup diagram.JPG

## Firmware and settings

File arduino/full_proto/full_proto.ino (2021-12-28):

/* backscatter sensing - full prototype 
 * eli baum // nsap capstone, 2021
 */

#include "fsk.h"
#include "msg_queue.h"

#define REQUESTED_CENTER_FREQ 150000

#define RED_LED 13
#define GREEN_LED 6
#define BUTTON 12
#define MAG_PIN A0

#define MEAS_AVG_LEN 64

#define PACKET_SIZE 16
#define PACKET_NULL 16
#define ACCESS_CODE_LENGTH 4
const uint8_t ACCESS_CODE[ACCESS_CODE_LENGTH] = {0xe1, 0x5a, 0xe8, 0x93};

uint16_t packet_bytes = 0;
uint8_t sqn = 0;

void enqueue_access_code() {
    for (int i = 0; i < ACCESS_CODE_LENGTH; i++) {
        enqueue_block(ACCESS_CODE[i]);
    }
}

// TOOD: add null region before this
void enqueue_packet_header() {
    enqueue_access_code();
    enqueue_block(sqn++);
    enqueue_block(PACKET_SIZE);
}

static char serial_buffer[128];

unsigned long start_t;

void setup() {
    Serial.begin(115200);
    Serial.println(F("\n====\nBackscatter sensing [prototype]"));
    Serial.println(F("NSAP Capstone Project, 2021\n"));
    Serial.println(F("Build " __DATE__ " " __TIME__ "\n"));

    pinMode(BUTTON, INPUT_PULLUP);

    Serial.println(F("Press enter or button to start..."));
    while (! Serial.available() && digitalRead(BUTTON)) { }
    Serial.read();

    pinMode(RED_LED, OUTPUT);
    pinMode(GREEN_LED, OUTPUT);
    digitalWrite(RED_LED, HIGH);

    Serial.println(F("Starting transmit..."));

    setup_io();
    setup_timers(REQUESTED_CENTER_FREQ);

    // preload queue
    enqueue_packet_header();

    start_t = millis();
}

volatile unsigned long sent_bits = 0;
unsigned long num_readings = 0;

void loop() {
    digitalWrite(RED_LED, HIGH);
    // get queue empty spots
    int spots = queue_empty_spots();

    sprintf(serial_buffer, "Filling %d spots", spots);
    Serial.println(serial_buffer);

    for (int i = 0; i < spots; i++) {
        digitalWrite(GREEN_LED, HIGH);
        long r = 0;
        for (int j = 0; j < MEAS_AVG_LEN; j++) {
            r += analogRead(MAG_PIN);
        }
        r /= MEAS_AVG_LEN;
        // TODO: deal with 10 bit issue :)
        enqueue(r >> 2);
        num_readings++;
        packet_bytes++;

        // if we've filled packet, start again
        if (packet_bytes >= PACKET_SIZE) {
            digitalWrite(GREEN_LED, LOW);
            sprintf(serial_buffer, "\t== pkt, last reading %ld ==", r);
            Serial.println(serial_buffer);
            long elapsed = millis() - start_t;
            sprintf(serial_buffer, "\t== %ld bps, %ld meas/sec ==",
                        1000 * sent_bits / elapsed,
                        1000 * num_readings / elapsed);
            Serial.println(serial_buffer);
            enqueue_packet_header();
            packet_bytes = 0;
        }
    }
    digitalWrite(GREEN_LED, LOW);
    
    delay(50);
}



volatile char data_index = 0;
volatile char bit_index = 0;

volatile uint8_t data = 0;

// send data MSB first
inline char get_bit() {
    if (bit_index < 0) {
        int d = dequeue();

        if (d == QUEUE_EMPTY) {
            // Serial.print("Qe");
            digitalWrite(RED_LED, LOW);
            return 0;
        }

        data = (uint8_t) d;

        // data_index++;

        // if (data_index >= ACCESS_CODE_LENGTH) {
        //     data_index = 0;
        // }

        // If I do Hamming, would go here.

        bit_index = 7;
    }

    sent_bits += 1;

    char b = !!(data & _BV(bit_index));
    bit_index--;
    return b;
}

volatile boolean need_new_bit = true;
volatile char bit;

/* 1 ms data timer
 * actually on sending one full bit every other, since we need the
 * intra-symbol transition
 *
 * 0 = short short
 * 1 = long
 */
ISR(TIMER2_COMPA_vect) {
    if (need_new_bit) {
        // get next bit
        bit = get_bit();
        toggle_ask();
        need_new_bit = false;
    } else {
        if (bit == 0) {
            toggle_ask();
        }
        // otherwise (bit == 1) do nothing
        need_new_bit = true;
    }
}

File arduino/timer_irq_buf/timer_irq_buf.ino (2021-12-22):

/* Send a message by modulating a signal.

   In this version, use a timer interrupt for FSK modulation,
   rather than pesky delays.

   Timer 1 handles the baseband
   Timer 2 handles the IRQ and modulation

   Prescale of 64 with count 250 gives exactly 1 kHz.

*/

#include "message.h"

// OC1A: PORT B1 (uno 9) **
// OC1B: PORT B2 (uno 10)

const int CTRL_1_PIN = 10;
const int CTRL_2_PIN = 9;

#define BASEBAND_PRESCALE (1)

#define BITS_PER_SECOND 1000
#define BIT_PRESCALE    64
#define BIT_OCR       (F_CPU / BIT_PRESCALE / BITS_PER_SECOND - 1)

inline void set_count(long c) {
  OCR1A = c;

  // if current count is greater than max val, we won't hit until
  // rollover... so reset.
  // Mod looks cleaner than just setting to zero; tbd.
  if (TCNT1 >= c) {
    TCNT1 %= c;
  }

}

long count_from_freq(long freq) {
  return F_CPU / BASEBAND_PRESCALE / 2 / freq - 1;
}

double freq_from_count(long count) {
  return (double)F_CPU / BASEBAND_PRESCALE / 2 / (1 + count);
}

const long REQ_CENTER_FREQ = 200000;
const long REQ_DEV_FREQ    =   5000;

long count_one, count_zero;

char serial_buffer[256];

#define RADIO_BUFFER_MAX 64

char radio_buffer[RADIO_BUFFER_MAX];

uint16_t rb_index = 0;
uint8_t rb_bit_index = 0;



ISR(TIMER2_COMPA_vect) {
  send_bit(radio_buffer[rb_index] & _BV(rb_bit_index));

  // send MSB to LSB
  if (rb_bit_index == 0) {
    rb_bit_index = 7;
    rb_index++;

    // wrap around if @ end
    if (rb_index >= RADIO_BUFFER_MAX) {
      rb_index = 0;
    }
  } else {
    rb_bit_index--;
  }
}

void setup() {
  // put your setup code here, to run once:
  pinMode(CTRL_1_PIN, OUTPUT);
  pinMode(CTRL_2_PIN, OUTPUT);

  digitalWrite(CTRL_1_PIN, LOW);
  digitalWrite(CTRL_2_PIN, LOW);

  Serial.begin(115200);
  Serial.println("\n\n\n");

  long high_count = count_from_freq(REQ_CENTER_FREQ + REQ_DEV_FREQ);
  long low_count = count_from_freq(REQ_CENTER_FREQ - REQ_DEV_FREQ);
  if (high_count == low_count) {
    Serial.println("ERROR! Not enough timer precision. Increase deviation frequency.");
    for (;;) { }
  }
  double actual_low_f  = freq_from_count(low_count);
  double actual_high_f = freq_from_count(high_count);

  double actual_center_f = (actual_low_f + actual_high_f) / 2;

  sprintf(serial_buffer, "Requested %ld +/- %ld Hz", REQ_CENTER_FREQ, REQ_DEV_FREQ);
  Serial.println(serial_buffer);

  Serial.print("Got "); Serial.print(actual_center_f);
  sprintf(serial_buffer, " (+%d, -%d) Hz",
          (int)(actual_high_f - actual_center_f),
          (int)(actual_center_f - actual_low_f));
  Serial.println(serial_buffer);

  sprintf(serial_buffer, "Counts %ld %ld", low_count, high_count);
  Serial.println(serial_buffer);

  Serial.println("Other options:");
  Serial.println("==Count==Freq======");

  for (long co = high_count - 1; co <= low_count + 1; co++) {
    char flag = ' ';

    if (co == low_count) {
      flag = 'L';
    } else if (co == high_count) {
      flag = 'H';
    }
    // can't printf floats
    sprintf(serial_buffer, "%c %5d  ", flag, co);
    Serial.print(serial_buffer);
    Serial.print(freq_from_count(co));
    Serial.println(" Hz");
  }

  Serial.print("Symb OCR2A: ");
  Serial.println(SYMB_OCR);

  sprintf(serial_buffer, "Sending message %s (len %d)",
          MESSAGE,
          strlen(MESSAGE));
  Serial.println(serial_buffer);

  count_one = high_count;
  count_zero = low_count;

  // load up the buffer
  // zero first
  for (int i = 0; i < RADIO_BUFFER_MAX; i++) {
    radio_buffer[i] = 0;
  }

  // load data
  int p = 0;
  // preamble 0xace4, 1010110011100100
  radio_buffer[p++] = (char)0xac;
  radio_buffer[p++] = (char)0xe4;
  strlcpy(&radio_buffer[p], MESSAGE, RADIO_BUFFER_MAX - 2);

  for (int i = 0; i < RADIO_BUFFER_MAX; i++) {
    Serial.println(radio_buffer[i], HEX);
  }

  ///////////////////////////
  // TURN ON THE TIMERS!

  // Set up baseband timer
  // Toggle OC1B (pin 10) on timer compare
  TCCR1A = _BV(COM1B0);
  // CTC with no prescale
  TCCR1B = _BV(WGM12) | _BV(CS10);

  // Set up modulator timer (interrupt)
  TCCR2A = _BV(WGM21); // CTC
  TCCR2B = _BV(CS22); // 64 prescale
  TIMSK2 = _BV(OCIE2A); // interrupt

  OCR2A = BIT_OCR;
}

//
//inline void send_length() {
//  int msg_len = strlen(MESSAGE);
//  // GNURadio wants it twice
//  send_byte((msg_len >> 8) & 0xFF);
//  send_byte(msg_len & 0xFF);
//  send_byte((msg_len >> 8) & 0xFF);
//  send_byte(msg_len & 0xFF);
//}

void loop() {
  //  Serial.print(rb_index); Serial.print(" "); Serial.println(rb_bit_index);
  //  delay(200);
}

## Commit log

2021-09-20 basic testing with switch
2021-09-20 basic (wired) FSK
2021-10-26 generate code table
    [8b10b.tsv]
2021-10-27 finally producing codes
    [8b10b.tsv]
2021-10-27 properly handle RD
    [8b10b.tsv]
2021-10-28 begin c impl of encoder
2021-11-10 more backscatter, bandpass, switching test
2021-11-10 start working on case
    [case.scad]
2021-11-12 align holes with datasheet; export
    [case.scad, case_v1.stl]
2021-11-17 now working on ask
    [case_v1_inch.stl]
2021-11-29 add analog sensor tests
2021-12-08 OTA counter with error metric
    [ask_test.ino]
2021-12-14 further sensor work, decided on mag
2022-08-01 add PRS case #
